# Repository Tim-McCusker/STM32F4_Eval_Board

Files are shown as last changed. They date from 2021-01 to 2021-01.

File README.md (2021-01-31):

# STM32F4 Evaluation Board

## My version of Phil's Labs' STM32F4 Evaluation Board and my first PCB design attempt. ##  

Key enhancements in my version of the project include: 
- Added ST Microelectronics i-NEMO I2C Inerital Measurement Unit 
- Added on-board temperature sensor 
- Alternate DC/DC Converter selection and power electronics circuitry 
- R2D2  

Please also check out the original design and tutorial series: 
    
GitHub: https://github.com/pms67/STM32F4-Reference-PCB

YouTube: https://www.youtube.com/channel/UCVryWqJ4cSlbTSETBHpBUWw

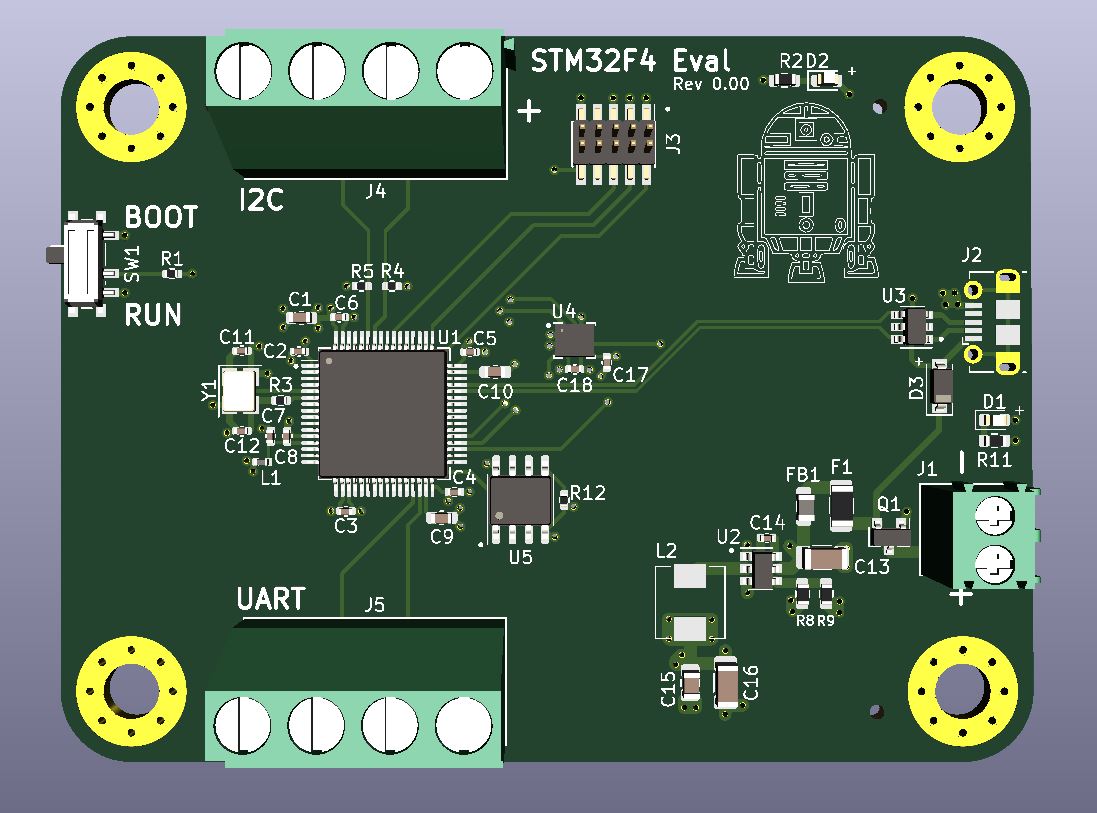
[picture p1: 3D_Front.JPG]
3D_FRONT_PCB


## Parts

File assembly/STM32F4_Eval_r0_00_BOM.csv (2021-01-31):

Comment | Designator | Footprint | LCSC Part #
4u7 Unpolarized capacitor, small symbol | C1 | C_0603_1608Metric | C19666
100n Unpolarized capacitor, small symbol | C2,C3,C4,C5,C6,C17,C18 | C_0402_1005Metric | C1525
1u Unpolarized capacitor, small symbol | C7 | C_0402_1005Metric | C52923
10n Unpolarized capacitor, small symbol | C8 | C_0402_1005Metric | C15195
2u2 Unpolarized capacitor, small symbol | C9,C10 | C_0603_1608Metric | C23630
12p Unpolarized capacitor, small symbol | C11,C12 | C_0402_1005Metric | C1547
22u Unpolarized capacitor, small symbol | C13 | C_1206_3216Metric | C50254
47n Unpolarized capacitor, small symbol | C14 | C_0402_1005Metric | C26403
150p Unpolarized capacitor, small symbol | C15 | C_0805_2012Metric | C1716
47u Unpolarized capacitor, small symbol | C16 | C_1206_3216Metric | C96123
Red Light emitting diode, small symbol | D1 | LED_0603_1608Metric | C2286
Blue Light emitting diode, small symbol | D2 | LED_0603_1608Metric | C72041
B5819W Schottky diode, small symbol | D3 | D_SOD-123 | C8598
1.5A Resettable fuse, polymeric positive temperature coefficient, small symbol | F1 | Fuse_1206_3216Metric | C369159
600 @ 600MHz Ferrite bead, small symbol | FB1 | L_0805_2012Metric | C1017
MountingHole_Pad Mounting Hole with connection | H1,H2,H3,H4 | MountingHole_4.3mm_M4_Pad_Via
12V_IN Generic screw terminal, single row, 01x02, script generated (kicad-library-utils/schlib/autogen/connector/) | J1 | TerminalBlock_Phoenix_PT-1,5-2-3.5-H_1x02_P3.50mm_Horizontal
USB USB Micro Type B connector | J2 | USB_Micro-B_Molex-105017-0001
SWD Generic connector, double row, 02x05, odd/even pin numbering scheme (row 1 odd numbers, row 2 even numbers), script generated (kicad-library-utils/schlib/autogen/connector/) | J3 | PinHeader_2x05_P1.27mm_Vertical_SMD
I2C Generic screw terminal, single row, 01x04, script generated (kicad-library-utils/schlib/autogen/connector/) | J4 | TerminalBlock_Phoenix_MKDS-1,5-4-5.08_1x04_P5.08mm_Horizontal
UART Generic screw terminal, single row, 01x04, script generated (kicad-library-utils/schlib/autogen/connector/) | J5 | TerminalBlock_Phoenix_MKDS-1,5-4-5.08_1x04_P5.08mm_Horizontal
39n Inductor, small symbol | L1 | L_0402_1005Metric | C26443
3u3 Inductor, small symbol | L2 | L_Sunlord_MWSA0518_5.4x5.2mm | C408410
AO3401A -4.0A Id, -30V Vds, P-Channel MOSFET, SOT-23 | Q1 | SOT-23 | C15127
10k Resistor, small symbol | R1,R12 | R_0402_1005Metric | C25744
1k5 Resistor, small symbol | R2 | R_0603_1608Metric | C22843
47 Resistor, small symbol | R3 | R_0402_1005Metric | C25792
2k2 Resistor, small symbol | R4,R5 | R_0402_1005Metric | C25879
33k Resistor, small symbol | R8 | R_0603_1608Metric | C4216
10k Resistor, small symbol | R9 | R_0603_1608Metric | C25804
1k Resistor, small symbol | R11 | R_0603_1608Metric | C21190
SW_SPDT Switch, single pole double throw | SW1 | SW_SPDT_PCM12
STM32F405RGT6 ARM Cortex-M4 MCU, 1024KB flash, 128KB RAM, 168MHz, 1.8-3.6V, 51 GPIO, LQFP-64 | U1 | LQFP-64_10x10mm_P0.5mm | C15742
RY8122 | U2 | SOT-23-6 | C370758
USBLC6-2SC6 Very low capacitance ESD protection diode, 2 data-line, SOT-23-6 | U3 | SOT-23-6 | C7519
LSM6DS3 I2C/SPI, iNEMO inertial module: always-on 3D accelerometer and 3D gyroscope | U4 | LGA-14_3x2.5mm_P0.5mm_LayoutBorder3x4y | C95231
LM335ADT | U5 | SOIC-8_3.9x4.9mm_P1.27mm | C361027
16MHz Four pin crystal, GND on pins 2 and 4, small symbol | Y1 | Crystal_SMD_3225-4Pin_3.2x2.5mm | C13738

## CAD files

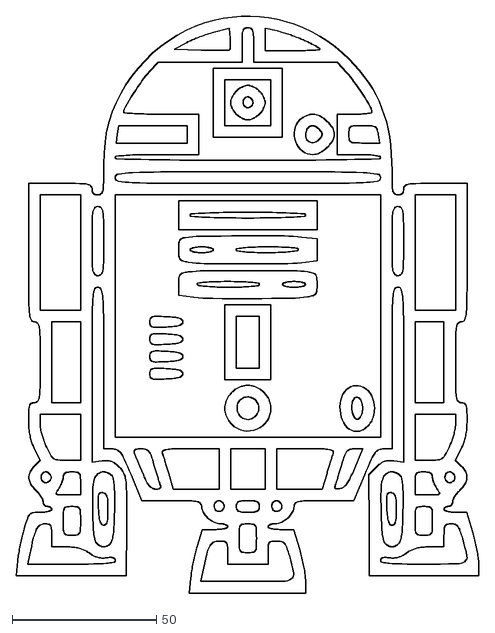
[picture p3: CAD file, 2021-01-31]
r2d2-icon-22.dxf
160.2 x 200.0

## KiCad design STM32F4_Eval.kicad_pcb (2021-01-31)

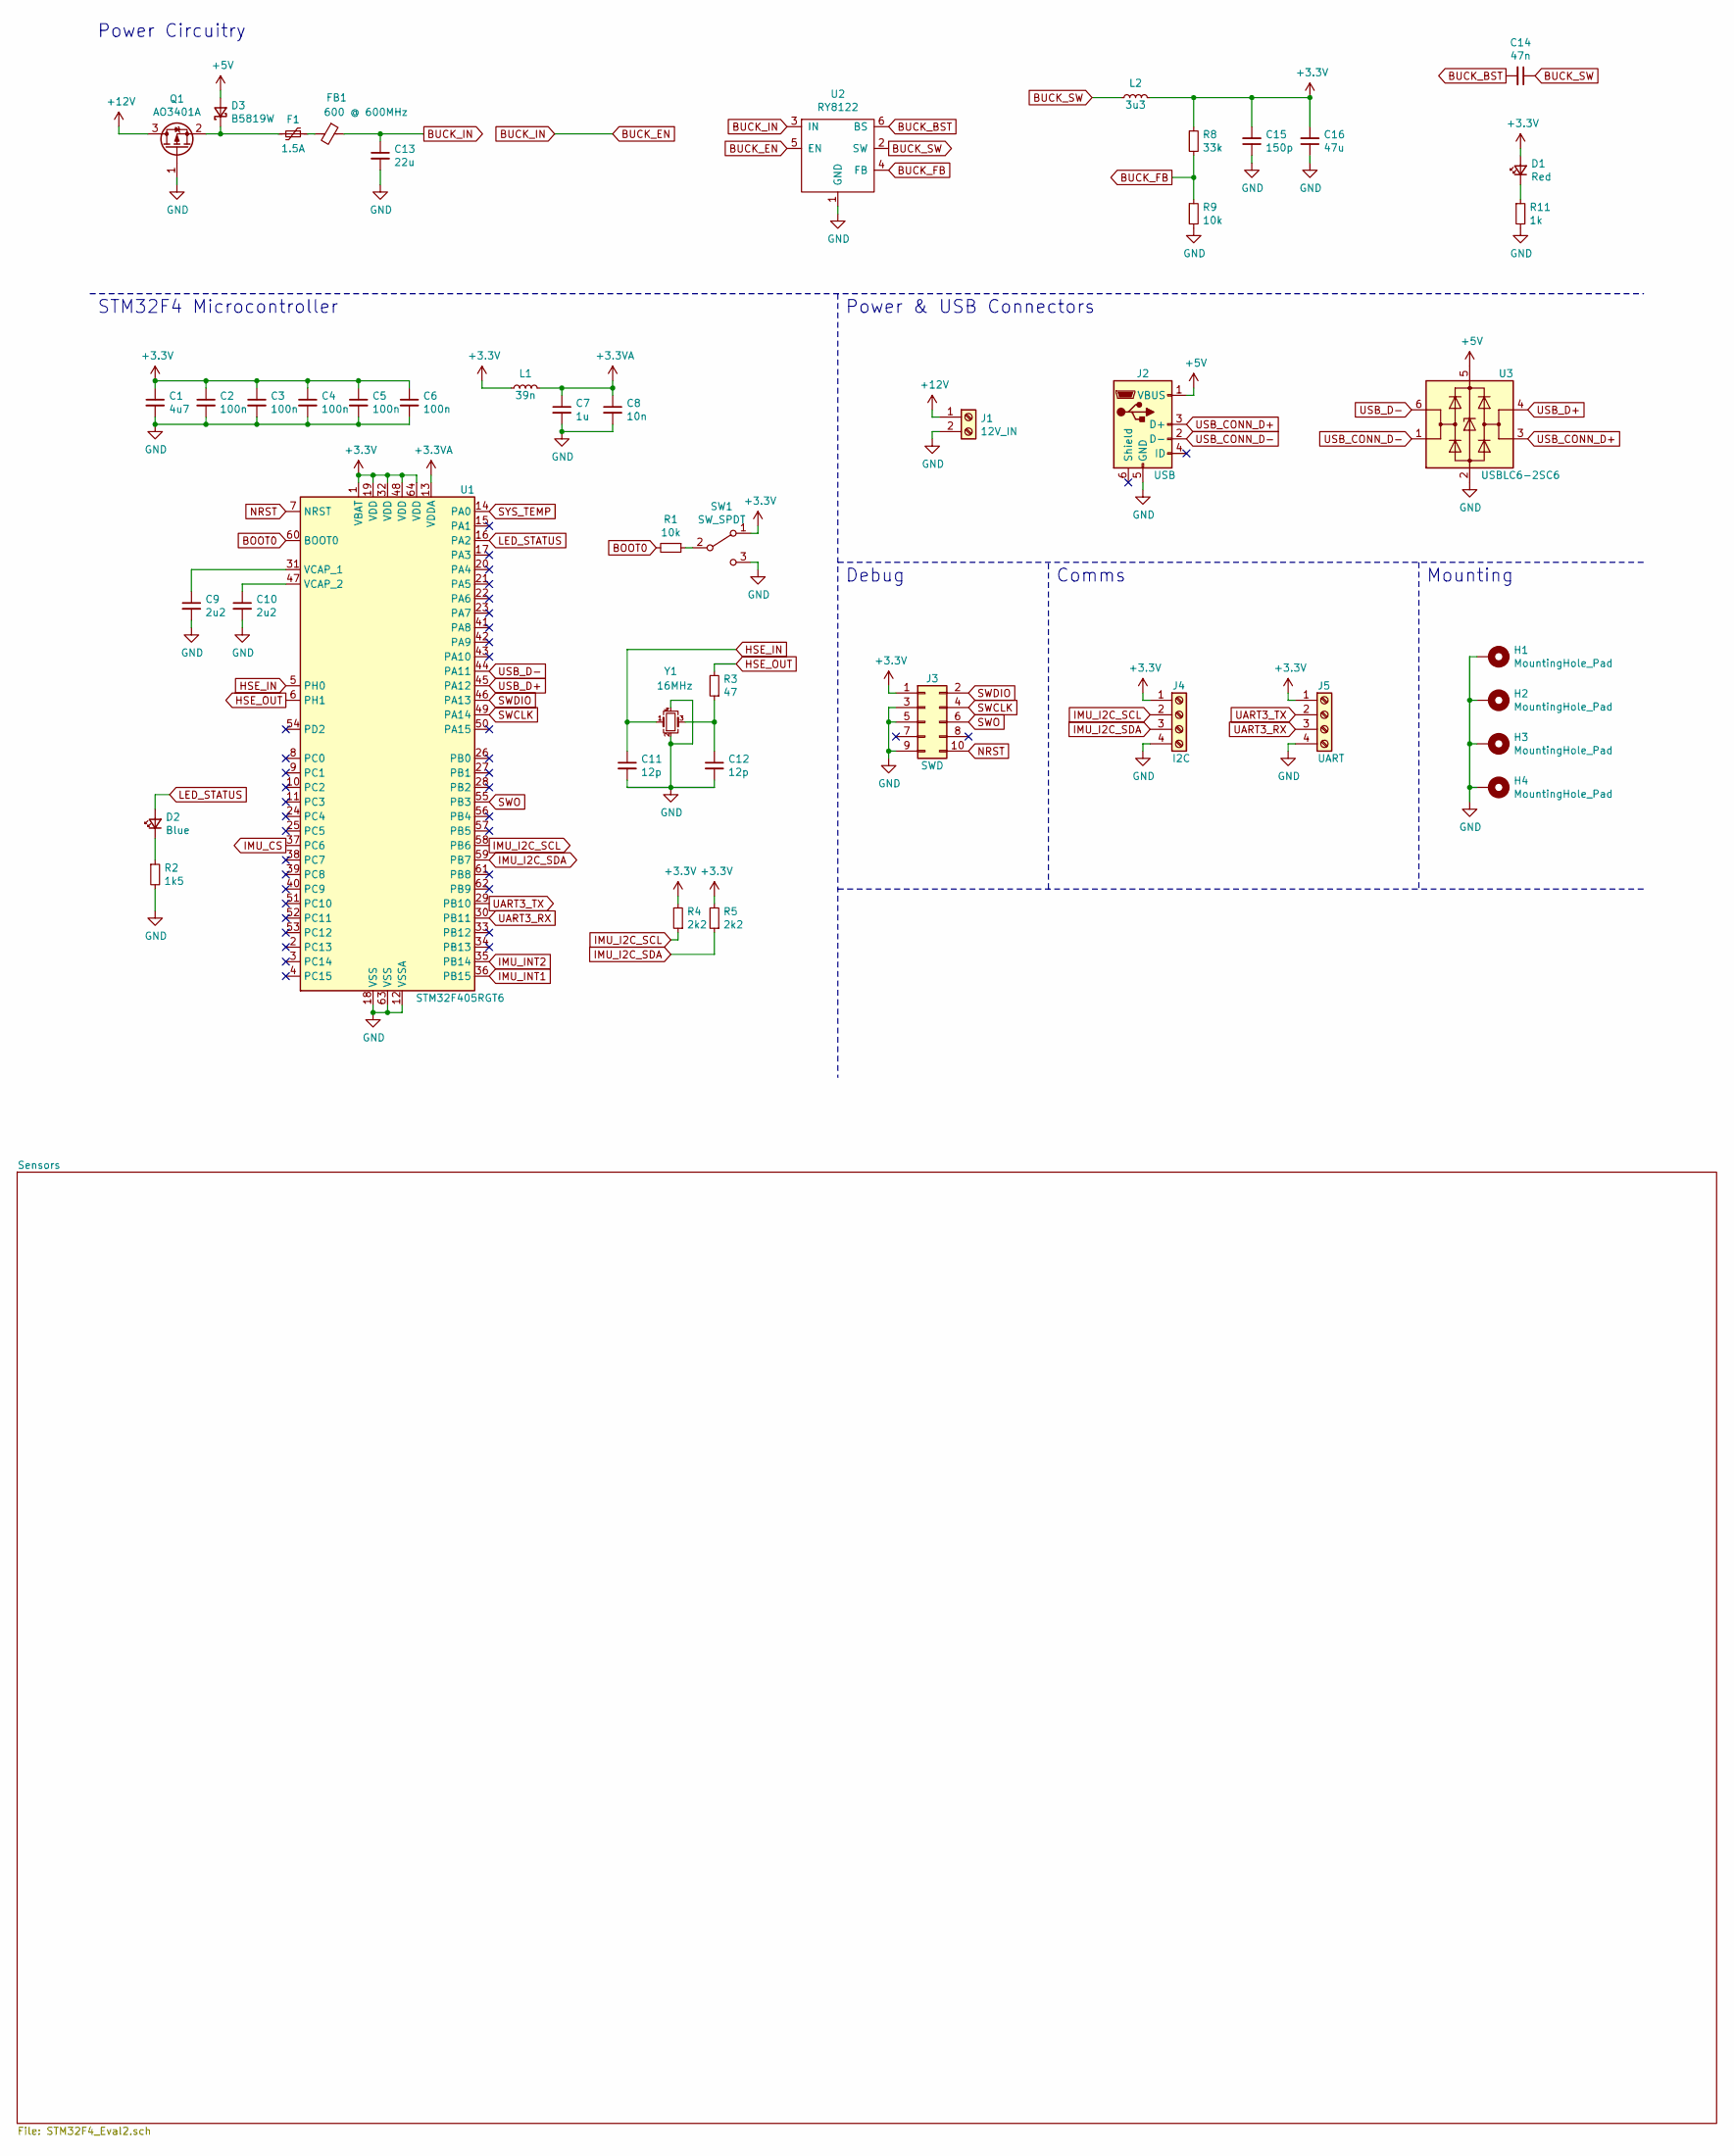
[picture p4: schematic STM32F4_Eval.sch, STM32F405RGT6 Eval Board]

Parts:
C1: 4u7; C_0603_1608Metric; LCSC Part # C19666
C2, C3, C4, C5, C6: 100n; C_0402_1005Metric; LCSC Part # C1525
C7: 1u; C_0402_1005Metric; LCSC Part # C52923
C8: 10n; C_0402_1005Metric; LCSC Part # C15195
C9, C10: 2u2; C_0603_1608Metric; LCSC Part # C23630
C11, C12: 12p; C_0402_1005Metric; LCSC Part # C1547
C13: 22u; C_1206_3216Metric; LCSC Part # C50254
C14: 47n; C_0402_1005Metric; LCSC Part # C26403
C15: 150p; C_0805_2012Metric; LCSC Part # C1716
C16: 47u; C_1206_3216Metric; LCSC Part # C96123
D1: Red; LED_0603_1608Metric; LCSC Part # C2286
D2: Blue; LED_0603_1608Metric; LCSC Part # C72041
D3: B5819W; D_SOD-123; LCSC Part # C8598
F1: 1.5A; Fuse_1206_3216Metric; LCSC Part # C369159
FB1: 600 @ 600MHz; L_0805_2012Metric; LCSC Part # C1017
H1, H2, H3, H4: MountingHole_Pad; MountingHole_4.3mm_M4_Pad_Via
J1: 12V_IN; TerminalBlock_Phoenix_PT-1,5-2-3.5-H_1x02_P3.50mm_Horizontal
J2: USB; USB_Micro-B_Molex-105017-0001
J3: SWD; PinHeader_2x05_P1.27mm_Vertical_SMD
J4: I2C; TerminalBlock_Phoenix_MKDS-1,5-4-5.08_1x04_P5.08mm_Horizont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
J5: UART; TerminalBlock_Phoenix_MKDS-1,5-4-5.08_1x04_P5.08mm_Horizont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
L1: 39n; L_0402_1005Metric; LCSC Part # C26443
L2: 3u3; L_Sunlord_MWSA0518_5.4x5.2mm; LCSC Part # C408410
Q1: AO3401A; SOT-23; LCSC Part # C15127
R1: 10k; R_0402_1005Metric; LCSC Part # C25744
R2: 1k5; R_0603_1608Metric; LCSC Part # C22843
R3: 47; R_0402_1005Metric; LCSC Part # C25792
R4, R5: 2k2; R_0402_1005Metric; LCSC Part # C25879
R8: 33k; R_0603_1608Metric; LCSC Part # C4216
R9: 10k; R_0603_1608Metric; LCSC Part # C25804
R11: 1k; R_0603_1608Metric; LCSC Part # C21190
SW1: SW_SPDT; SW_SPDT_PCM12
U1: STM32F405RGT6; LQFP-64_10x10mm_P0.5mm; LCSC Part # C15742
U2: RY8122; SOT-23-6; LCSC Part # C370758
U3: USBLC6-2SC6; SOT-23-6; LCSC Part # C7519
Y1: 16MHz; Crystal_SMD_3225-4Pin_3.2x2.5mm; LCSC Part # C13738

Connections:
+3.3VA: C7.1, C8.1, L1.2, U1.13 (VDDA)
+3V3: C1.1, C2.1, C3.1, C4.1, C5.1, C6.1, C15.2, C16.2, D1.2 (A), J3.1, J4.1, J5.1, L1.1, L2.2, R4.2, R5.2, R8.1, SW1.1 (A), U1.1 (VBAT), U1.19 (VDD), U1.32 (VDD), U1.48 (VDD), U1.64 (VDD); also elsewhere on the board
+5V: D3.2 (A), J2.1 (VBUS), U3.5 (VBUS)
+12V: J1.1, Q1.3 (D)
BOOT0: R1.2, U1.60 (BOOT0)
BUCK_BST: C14.2, U2.6 (BS)
BUCK_EN: C13.1, FB1.1, U2.3 (IN), U2.5 (EN)
BUCK_FB: R8.2, R9.1, U2.4 (FB)
BUCK_SW: C14.1, L2.1, U2.2 (SW)
GND: C1.2, C2.2, C3.2, C4.2, C5.2, C6.2, C7.2, C8.2, C9.2, C10.2, C11.2, C12.2, C13.2, C15.1, C16.1, H1.1, H2.1, H3.1, H4.1, J1.2, J2.5 (GND), J3.3, J3.5, J3.9, J4.4, J5.4, Q1.1 (G), R2.2, R9.2, R11.2, SW1.3 (C), U1.12 (VSSA), U1.18 (VSS), U1.63 (VSS), U2.1 (GND), U3.2 (GND), Y1.2, Y1.4; also elsewhere on the board
HSE_IN: C11.1, U1.5 (PH0), Y1.1
HSE_OUT: R3.2, U1.6 (PH1)
IMU_CS: U1.37 (PC6); also elsewhere on the board
IMU_I2C_SCL: J4.2, R4.1, U1.58 (PB6); also elsewhere on the board
IMU_I2C_SDA: J4.3, R5.1, U1.59 (PB7); also elsewhere on the board
IMU_INT1: U1.36 (PB15); also elsewhere on the board
IMU_INT2: U1.35 (PB14); also elsewhere on the board
LED_STATUS: D2.2 (A), U1.16 (PA2)
NRST: J3.10, U1.7 (NRST)
unnamed: C9.1, U1.31 (VCAP_1)
unnamed: C10.1, U1.47 (VCAP_2)
unnamed: C12.1, R3.1, Y1.3
unnamed: D1.1 (K), R11.1
unnamed: D2.1 (K), R2.1
unnamed: D3.1 (K), F1.2, Q1.2 (S)
unnamed: F1.1, FB1.2
unnamed: R1.1, SW1.2 (B)
SWCLK: J3.4, U1.49 (PA14)
SWDIO: J3.2, U1.46 (PA13)
SWO: J3.6, U1.55 (PB3)
SYS_TEMP: U1.14 (PA0); also elsewhere on the board
UART3_RX: J5.3, U1.30 (PB11)
UART3_TX: J5.2, U1.29 (PB10)
USB_CONN_D+: J2.3 (D+), U3.3 (I/O2)
USB_CONN_D-: J2.2 (D-), U3.1 (I/O1)
USB_D+: U1.45 (PA12), U3.4 (I/O2)
USB_D-: U1.44 (PA11), U3.6 (I/O1)

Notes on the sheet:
Power & USB Connectors
Debug
Comms
STM32F4 Microcontroller
Power Circuitry
Mounting

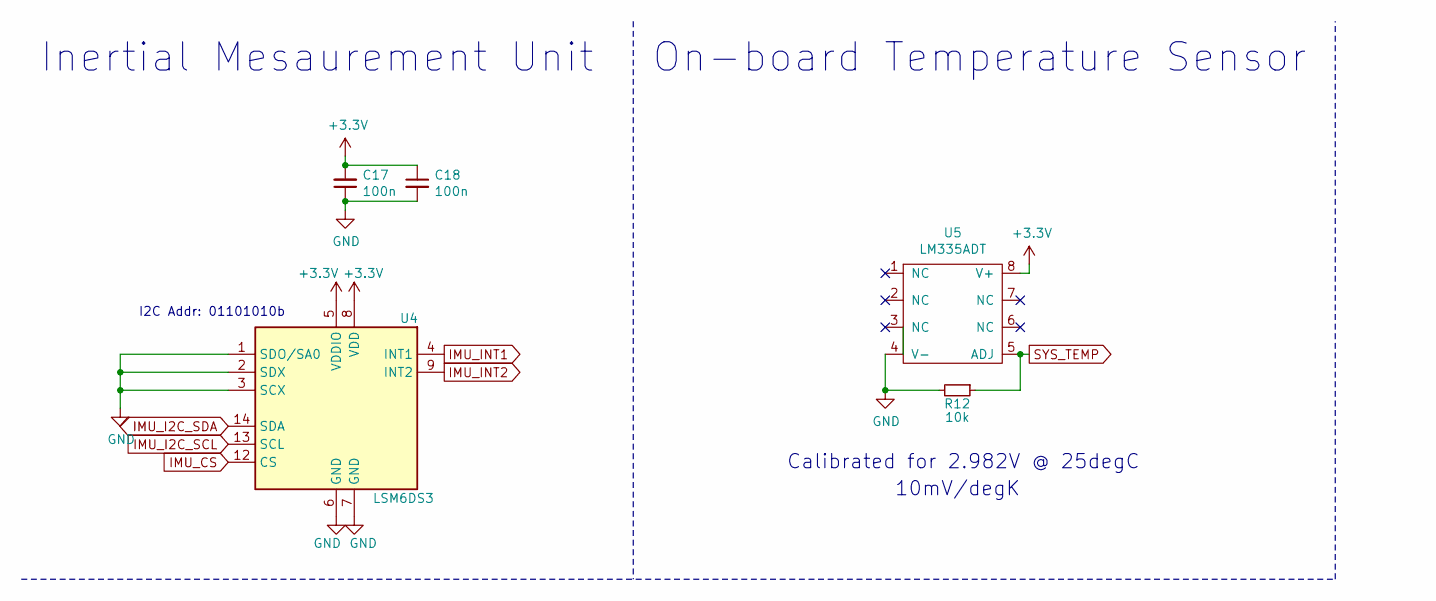
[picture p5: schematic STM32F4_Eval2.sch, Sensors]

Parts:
C17, C18: 100n; C_0402_1005Metric; LCSC Part # C1525
R12: 10k; R_0402_1005Metric; LCSC Part # C25744
U4: LSM6DS3; LGA-14_3x2.5mm_P0.5mm_LayoutBorder3x4y; LCSC Part # C95231
U5: LM335ADT; SOIC-8_3.9x4.9mm_P1.27mm; LCSC Part # C361027

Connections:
+3V3: C17.2, C18.1, U4.5 (VDDIO), U4.8 (VDD), U5.8 (V+); also elsewhere on the board
GND: C17.1, C18.2, R12.2, U4.1 (SDO/SA0), U4.2 (SDX), U4.3 (SCX), U4.6 (GND), U4.7 (GND), U5.4 (V-); also elsewhere on the board
IMU_CS: U4.12 (CS); also elsewhere on the board
IMU_I2C_SCL: U4.13 (SCL); also elsewhere on the board
IMU_I2C_SDA: U4.14 (SDA); also elsewhere on the board
IMU_INT1: U4.4 (INT1); also elsewhere on the board
IMU_INT2: U4.9 (INT2); also elsewhere on the board
SYS_TEMP: R12.1, U5.5 (ADJ); also elsewhere on the board

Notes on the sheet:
Inertial Mesaurement Unit
I2C Addr: 01101010b
On-board Temperature Sensor
Calibrated for 2.982V @ 25degC
10mV/degK

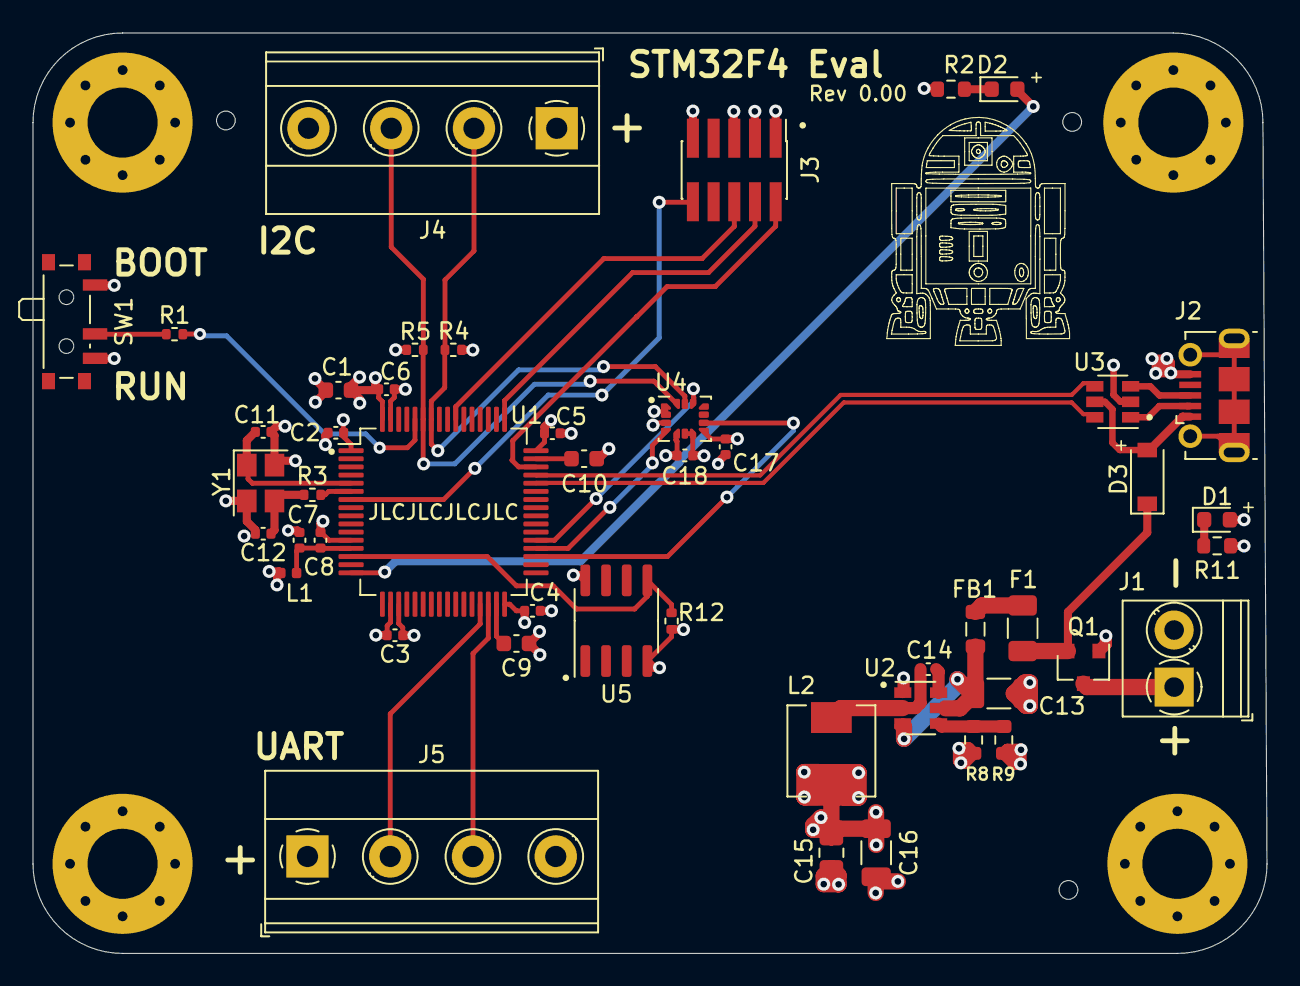
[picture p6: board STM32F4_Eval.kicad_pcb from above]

Board: 4 copper layers, 75.8 x 56.5 mm, 51 parts (0 on the bottom side), 37 nets.
